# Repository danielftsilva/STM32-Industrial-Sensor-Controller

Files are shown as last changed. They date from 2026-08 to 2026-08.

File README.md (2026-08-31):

# STM32-RF-USB-Gateway

## Overview

<p align="center">
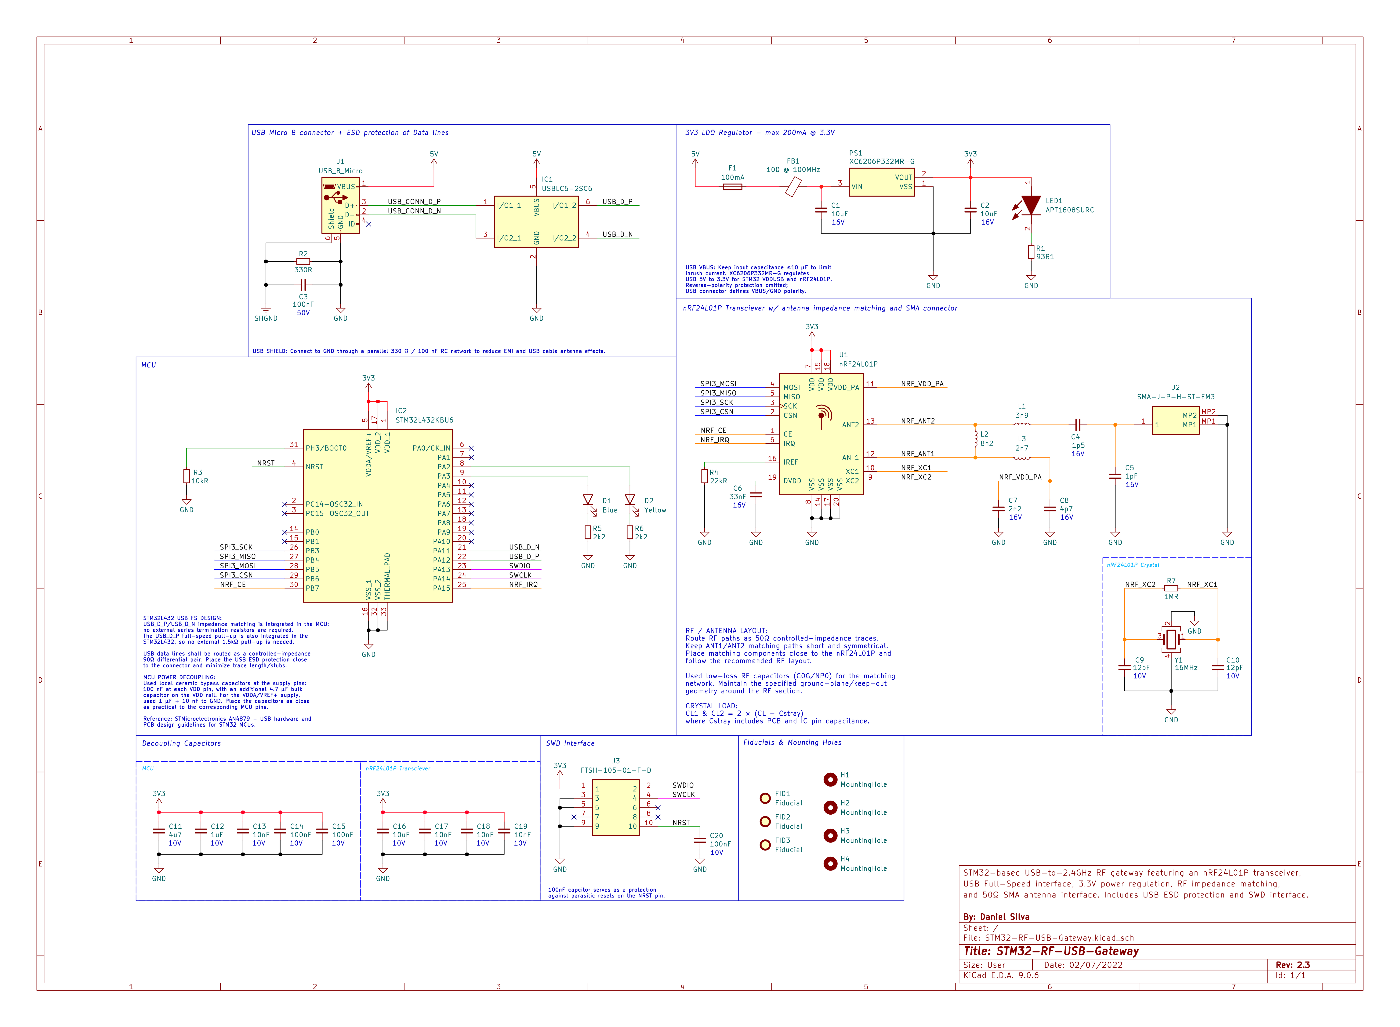
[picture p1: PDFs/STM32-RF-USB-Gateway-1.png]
  
</p>
<p align="center">
  <a href="PDFs/STM32-RF-USB-Gateway.pdf">
    View the complete schematic PDF
  </a>
</p>

The **STM32-RF-USB-Gateway** is an embedded hardware platform developed to provide a USB interface between a computer and a **2.4 GHz nRF24L01P wireless transceiver**.

The objective of the project is to develop a compact USB-connected wireless gateway based on the **STM32L432KBU6**, allowing the microcontroller to interface with a host computer through USB while controlling the nRF24L01P through SPI.

The design incorporates dedicated power regulation, USB ESD protection, a 16 MHz crystal oscillator, an RF impedance-matching network, a 50 Ω controlled-impedance antenna path, an external SMA connector, and an SWD programming/debugging interface.

## Main Components

- **STMicroelectronics STM32L432KBU6** — main microcontroller with USB Full-Speed and SPI interfaces
- **Nordic Semiconductor nRF24L01P** — 2.4 GHz wireless transceiver
- **Torex XC6206P332MR-G** — 3.3 V LDO regulator
- **STMicroelectronics USBLC6-2SC6** — USB ESD protection
- **Samtec SMA-J-P-H-ST-EM3** — 50 Ω SMA antenna connector
- **FTSH-105-01-F-D** — SWD programming/debugging connector
- **16 MHz crystal** — nRF24L01P reference clock

### STM32 Peripheral Assignment

The STM32L432KBU6 was configured as the central controller of the gateway, with its peripherals and GPIOs assigned to the USB, nRF24L01P, SWD, and status interfaces.

<p align="center">
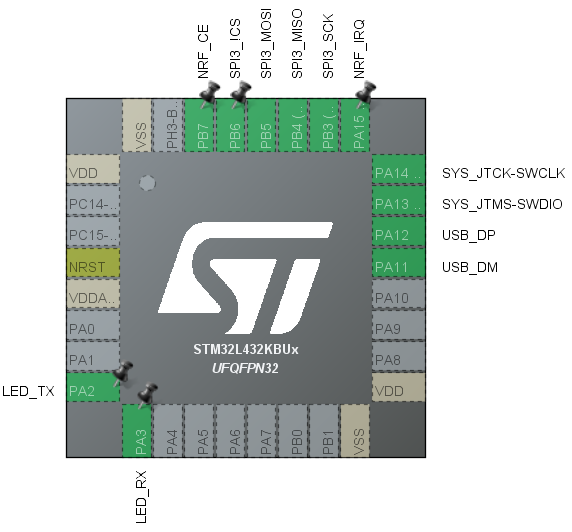
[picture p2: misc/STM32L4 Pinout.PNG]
  
</p>

<p align="center">
  <em>STM32L432KBU6 pin assignment used in the design</em>
</p>

## PCB Design

The PCB layout was developed from the finalized schematic, with dedicated areas for the USB interface, power regulation, STM32, nRF24L01P, RF matching network, SMA antenna interface, and SWD connector.

<p align="center">
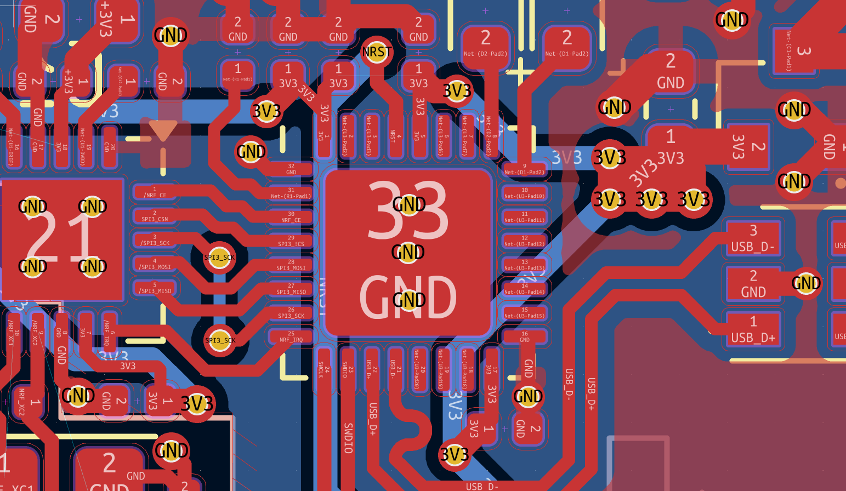
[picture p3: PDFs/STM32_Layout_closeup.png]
  
</p>

<p align="center">
  <em>Layout close-up of the STM32L432KBU6.</em>
</p>

The RF section was designed as a dedicated 50Ω controlled-impedance interface between the nRF24L01P matching network and the external SMA connector.

<p align="center">
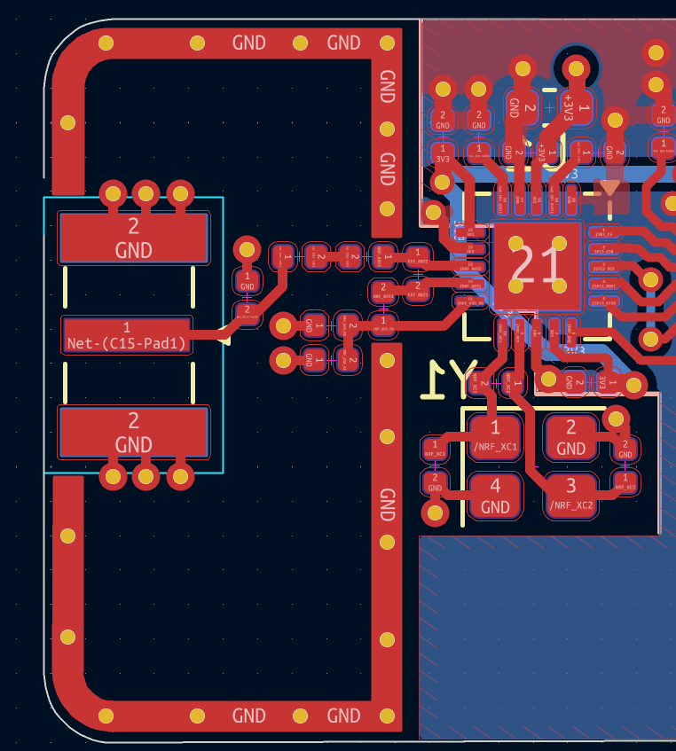
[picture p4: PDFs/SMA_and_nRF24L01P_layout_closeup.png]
  
</p>

<p align="center">
  <em>2.4 GHz RF matching network, controlled-impedance transmission line and SMA interface</em>
</p>

## Project Status

**Work in Progress**

- Project started: **2022**
- Objective: Exploration of the **STM32L432KBU6** and its capabilities
- Schematic: **Existing gateway architecture finalized**
- PCB layout: **In progress**
- Firmware: **Started, but not completed**
- Prototype: **Not yet completed**

The current repository documents the developed USB-to-2.4 GHz RF gateway hardware. The PCB layout is being expanded before finalization to incorporate additional functionality.

## Planned Expansion

The next revision is planned to include:

- **OLED display** for local system and RF status
- **User reset button**
- **I²C environmental sensor** for temperature, humidity, pressure, etc.
- **Additional test points** for hardware debugging and validation

These additions are the reason the current PCB layout remains unfinished. The existing gateway schematic is finalized, while the new features still need to be incorporated into the schematic and PCB before the hardware can be considered complete.

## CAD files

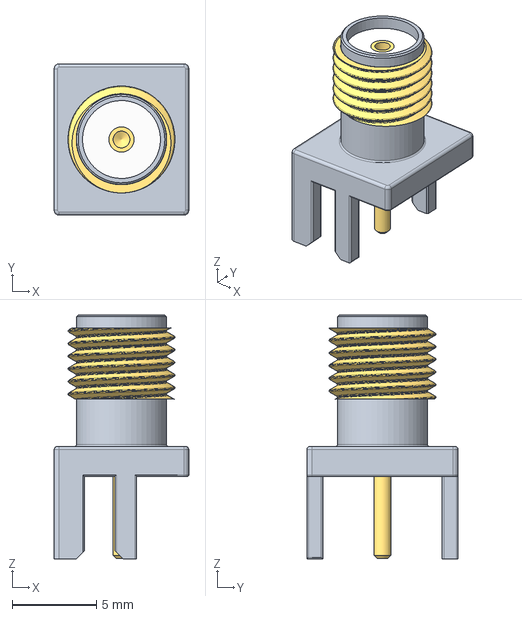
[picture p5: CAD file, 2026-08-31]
misc/SMA-20.stp
8.00 x 9.00 x 14.5 mm

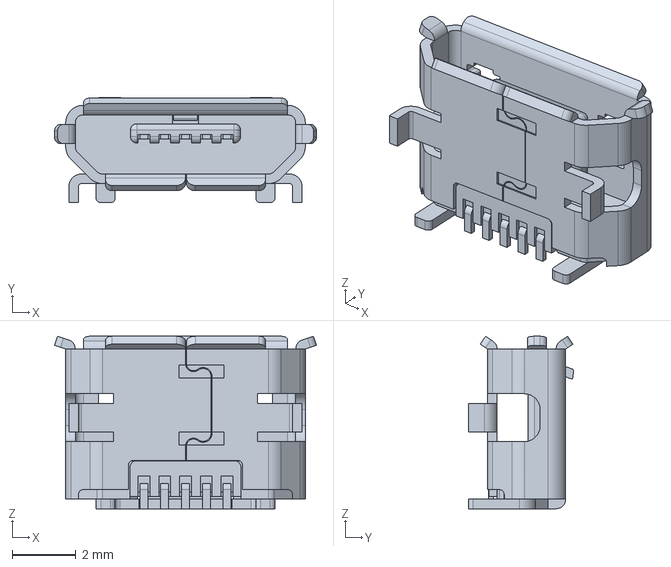
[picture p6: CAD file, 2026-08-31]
misc/1050170001.stp
8.20 x 3.30 x 5.40 mm

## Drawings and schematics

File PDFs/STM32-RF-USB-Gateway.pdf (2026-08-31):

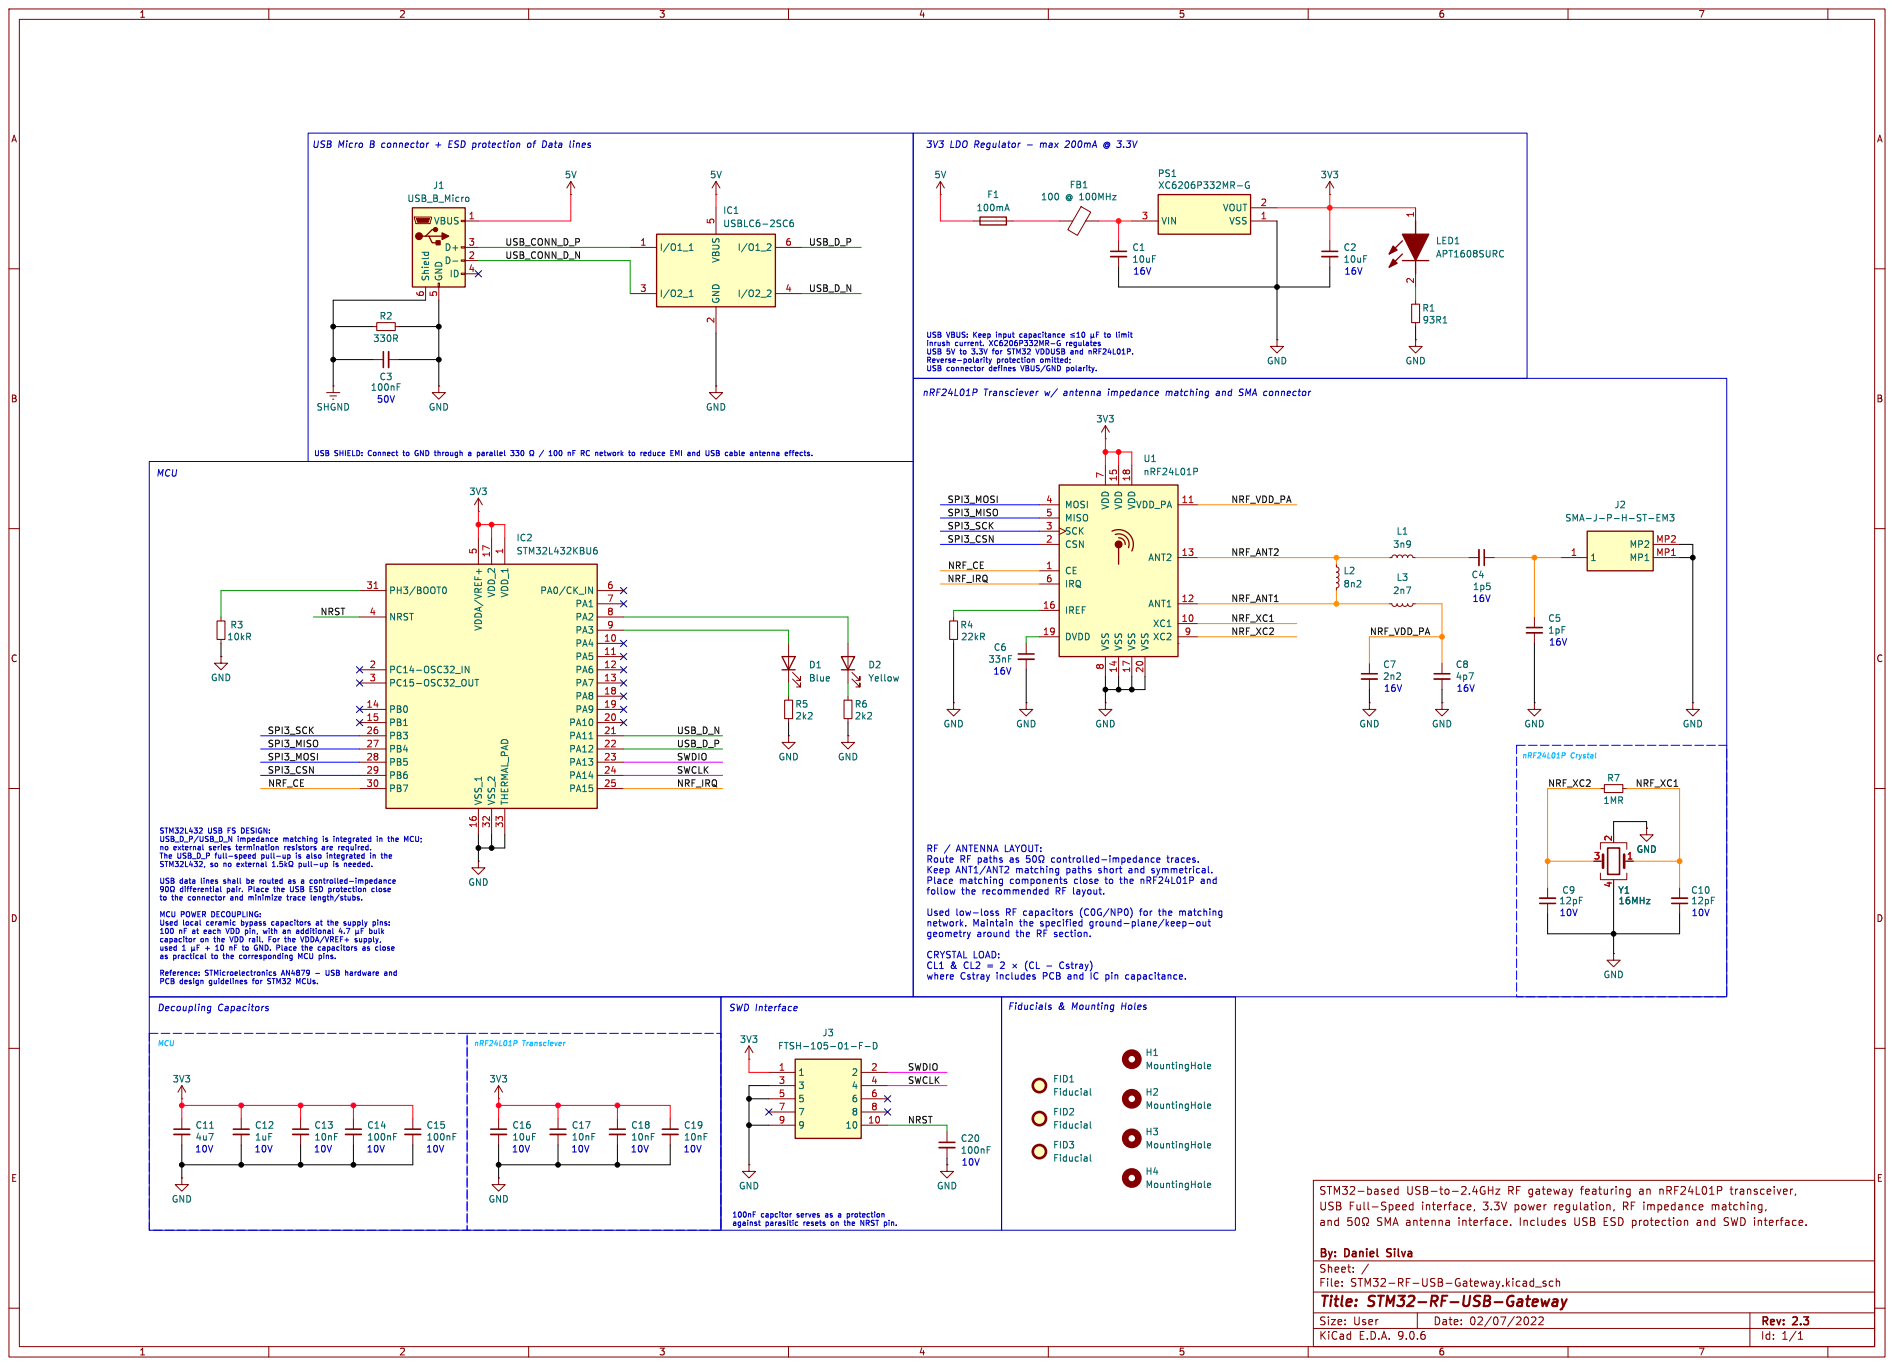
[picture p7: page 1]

3V3 LDO Regulator - max 200mA @ 3.3V MCU

8 VDD 15 VSS 14 VDD 18 VSS 17 VSS 20 VDD_PA 11 ANT2 13 ANT1 12 XC1 10 XC2 9 U1

Id: 1/1 Title: STM32-RF-USB-Gateway

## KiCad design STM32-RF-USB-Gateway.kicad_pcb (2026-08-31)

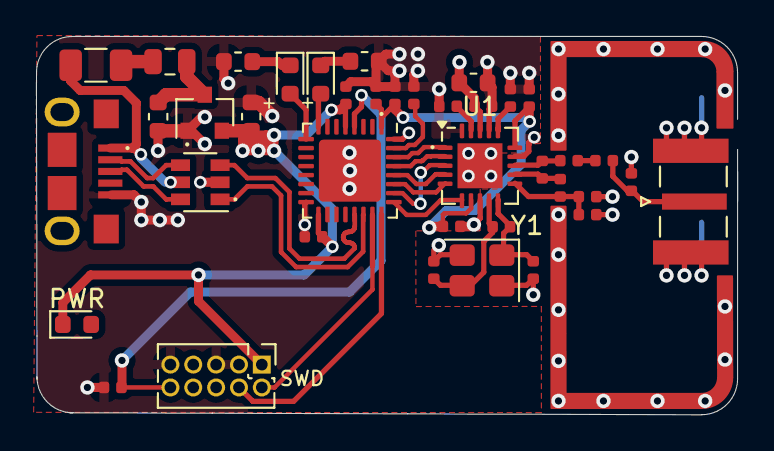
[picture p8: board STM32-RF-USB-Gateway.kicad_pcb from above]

Board: 4 copper layers, 39.0 x 21.0 mm, 39 parts (0 on the bottom side), 26 nets.

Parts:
C1, C2, C8: 10u; C_0603_1608Metric
C3, C5, C6, C7: 100n; C_0402_1005Metric
C4: 1u; C_0402_1005Metric
C9, C10, C11: 10n; C_0402_1005Metric
C12: 33n; C_0402_1005Metric
C13, C14: 12p; C_0402_1005Metric
C15: 1p5; C_0402_1005Metric
C16: 1p; C_0402_1005Metric
C17: 2n2; C_0402_1005Metric
C18: 4p7; C_0402_1005Metric
D1: GR; LED_0603_1608Metric
D2: YE; LED_0603_1608Metric
F1: 100mA; Fuse_1206_3216Metric
FB1: 100 @ 100MHz; L_0805_2012Metric
J1: USB_B_Micro; 101181930001LF
J2: SMA; SMA_Samtec_SMA-J-P-X-ST-EM1_EdgeMount
J3: ARM 10pin; PinHeader_2x05_P1.27mm_Vertical
L1: 3n9; L_0402_1005Metric
L2: 8n2; L_0402_1005Metric
L3: 2n7; L_0402_1005Metric
PWR: APT1608SURC; LED_0603_1608Metric
R1: 2k2; R_0402_1005Metric
R2, R3: 2k2; R_0603_1608Metric
R4: 22k; R_0402_1005Metric
R5: 1M; R_0402_1005Metric
U1: XC6206P332MR; SOT-23
U1#2: nRF24L01P; QFN-20-1EP_4x4mm_P0.5mm_EP2.5x2.5mm
U2: USBLC6-2SC6; SOT-23-6
U3: STM32L432KBU6; QFN-32-1EP_5x5mm_P0.5mm_EP3.45x3.45mm
Y1: 16MHz; Crystal_SMD_3225-4Pin_3.2x2.5mm

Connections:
3V3: C2.1, C4.1, C5.1, C6.1, C7.1, C9.1, C10.1, J3.1, PWR.1 (A), U1.2, U1#2.7 (VDD), U1#2.15 (VDD), U1#2.18 (VDD), U3.1, U3.5, U3.17
+3V3: C8.1, C11.1
+5V: F1.2, J1.1, U2.5
/NRF_XC1: U1#2.10 (XC1), Y1.1
/NRF_XC2: U1#2.9 (XC2), Y1.3
GND: C1.2, C2.2, C3.2, C4.2, C5.2, C6.2, C7.2, C8.2, C9.2, C10.2, C11.2, C12.2, C13.2, C14.2, C16.1, C17.1, C18.1, J1.5, J2.2, J3.3, J3.5, J3.9, R1.2, R2.2, R3.2, R4.2, U1.1, U1#2.8 (VSS), U1#2.14 (VSS), U1#2.17 (VSS), U1#2.20 (VSS), U2.2, U3.16, U3.32, U3.33, Y1.2, Y1.4
NRF_ANT1: L2.2, L3.2
NRF_ANT2: L1.1, L2.1
NRF_VDD_PA: C17.2, C18.2, L3.1
NRF_XC1: C13.1, R5.2
NRF_XC2: C14.1, R5.1
NRST: C3.1, J3.10, U3.4
unnamed: C1.1, U1.3
unnamed: C15.1, C16.2, J2.1
unnamed: C15.2, L1.2
unnamed: D1.1, R2.1
unnamed: D1.2, U3.9
unnamed: D2.1, R3.1
unnamed: D2.2, U3.8
unnamed: R1.1, U3.31
SWCLK: J3.4, U3.24
SWDIO: J3.2, U3.23
USB_CONN_D+: J1.3, U2.6
USB_CONN_D-: J1.2, U2.4
USB_D+: U2.1, U3.22
USB_D-: U2.3, U3.21

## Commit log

2026-08-31 Initial project commit
    [1050170001.stp, SMA-20.stp, STM32-RF-USB-Gateway.kicad_pcb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]
2026-08-31 Add schematic preview image
